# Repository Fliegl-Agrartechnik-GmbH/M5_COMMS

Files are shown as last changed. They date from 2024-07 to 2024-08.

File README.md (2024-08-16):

# M5_COMMS
M5_COMMS are CAN-Bus and Modbus Boards for M5 Stack

<https://github.com/espressif/esp-idf/issues/13989>

<https://community.m5stack.com/topic/306/plc-module/12?_=1718738548748>

4 Models: 
(right klick, open in new Tab for high-res view)

1. MAX3485, is a Fully 3.3V RS-485 Transceiver


2. LTC2877IMSE, is a 5V RS-485 Transceiver with a VIO Pin, so can interface to a 3.3V and even 1.8 V MCU


3. MAX485 is a 5V only Transceiver, using the Schottky Diode to not damage the ESP32 at RX.


4. CAN-Bus with a Infineon Transceiver

see: <https://github.com/Fliegl-Agrartechnik-GmbH/M5_COMMS/tree/main/CAN-BUS>
   


174776340480-Produce_DanZhi SMT_Snapshot Top 2790709A_Y380 SMT02407241857146 (1)

# lic
<p xmlns:cc="http://creativecommons.org/ns#" xmlns:dct="http://purl.org/dc/terms/"><a property="dct:title" rel="cc:attributionURL" href="https://github.com/Fliegl-Agrartechnik-GmbH/M5_COMMS">M5_COMMS</a> by <a rel="cc:attributionURL dct:creator" property="cc:attributionName" href="https://github.com/Fliegl-Agrartechnik-GmbH">Fliegl Agrartechnik GmbH</a> is licensed under <a href="https://creativecommons.org/licenses/by-sa/4.0/?ref=chooser-v1" target="_blank" rel="license noopener noreferrer" style="display:inline-block;">CC BY-SA 4.0</a></p>

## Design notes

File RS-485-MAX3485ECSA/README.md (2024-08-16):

# RS-485-MAX3485ECSA

## Pinout

| **RS-485** | **RXD** | **TXD** | **RTS** |
|---|---|---|---|
| Core (Basic) | G16 | G17 | G2 |
| Core 2 | G13 | G14 | G32 |
| CoreS3 | G18 | G17 | G2 |

## External

| **Pin**  | **1** | **2** | **3** | **4** |
|---|---|---|---|---|
| Function | DC 9-24V | B | A | GND |
| PROFIBUS | DC 9-24V | A | B | GND |

## Testing

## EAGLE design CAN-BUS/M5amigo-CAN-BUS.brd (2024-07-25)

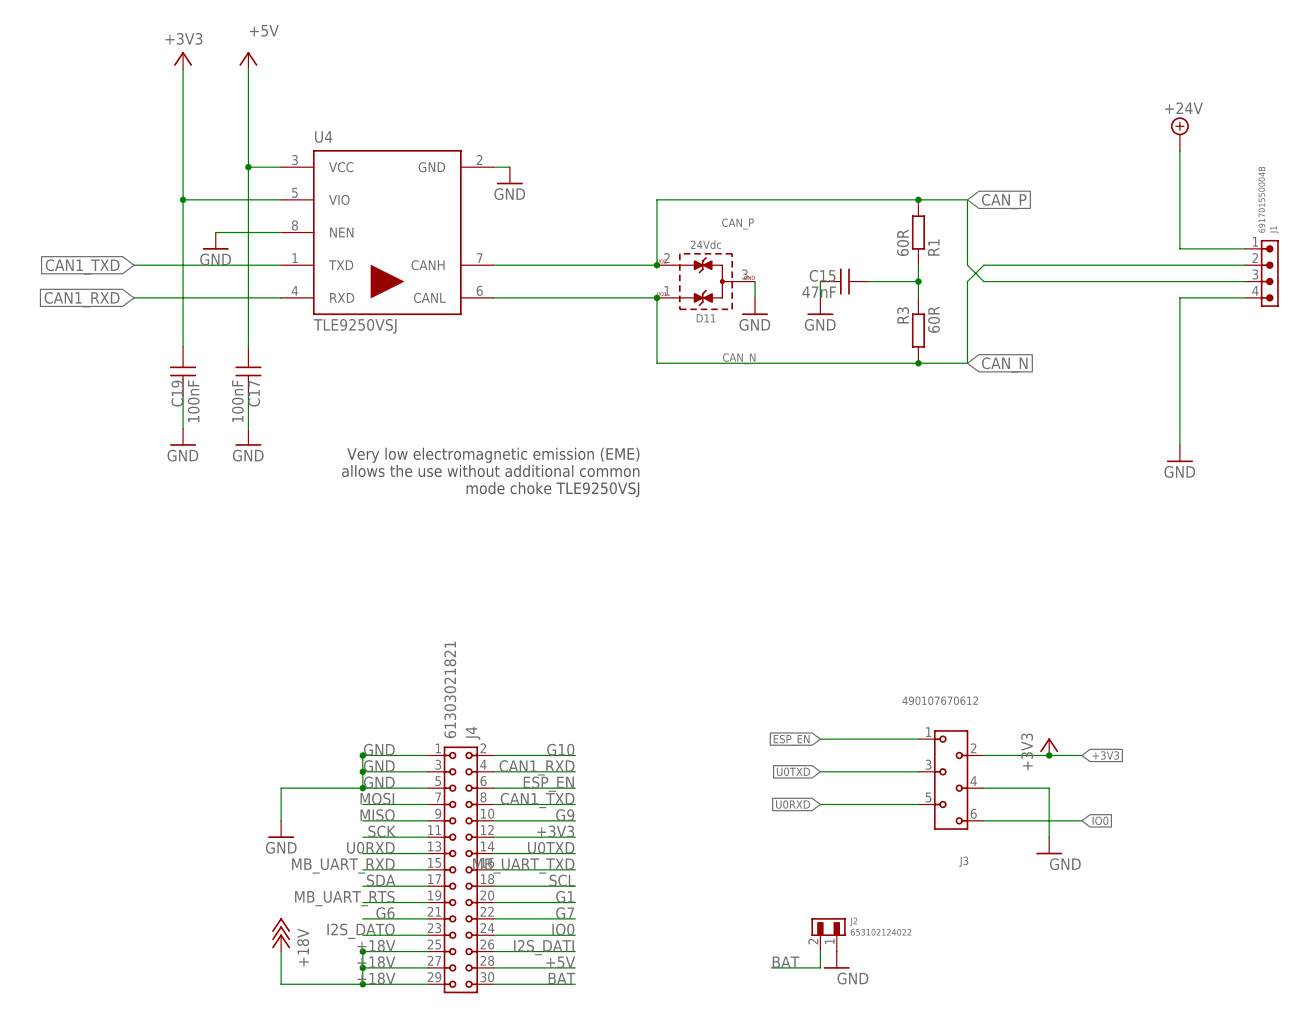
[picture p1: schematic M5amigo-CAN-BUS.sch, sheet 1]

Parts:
C15: 47nF; WCAP-CSGP_0805_H0.8_R
C17, C19: 100nF; WCAP-CSGP_0805_H0.8_R
D11: 24Vdc; WE-TVS_SOT23-3L
J1: 691701550004B
J2: 653102124022
J3: 490107670612; 490107670612_DEBUGGING
J4: 61303021821
R1, R3: 60R; R0805
U4: TLE9250VSJ; SOIC127P602X173-8N-V

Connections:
+3V3: C19.1, J3.2, J4.12, U4.5 (VIO)
+5V: C17.1, J4.28, U4.3 (VCC)
+18V: J4.25, J4.27, J4.29; also elsewhere on the board
+24V: J1.1; also elsewhere on the board
BAT: J2.2, J4.30
CAN1_RXD: J4.4, U4.4 (RXD)
CAN1_TXD: J4.8, U4.1 (TXD)
CAN_N: D11.1 (I/O1), J1.2, R3.2, U4.6 (CANL)
CAN_P: D11.2 (I/O2), J1.3, R1.2, U4.7 (CANH)
ESP_EN: J3.1, J4.6
G1: J4.20
G6: J4.21
G7: J4.22
G9: J4.10
G10: J4.2
GND: C15.2, C17.2, C19.2, D11.3 (GND), J1.4, J2.1, J3.4, J4.1, J4.3, J4.5, U4.2 (GND), U4.8 (NEN); also elsewhere on the board
I2S_DATI: J4.26
I2S_DATO: J4.23
IO0: J3.6, J4.24
MB_UART_RTS: J4.19
MB_UART_RXD: J4.15
MB_UART_TXD: J4.16
MISO: J4.9
MOSI: J4.7
unnamed: C15.1, R1.1, R3.1
SCK: J4.11
SCL: J4.18
SDA: J4.17
U0RXD: J3.5, J4.13
U0TXD: J3.3, J4.14

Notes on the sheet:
Very low electromagnetic emission (EME) allows the use without additional common mode choke TLE9250VSJ

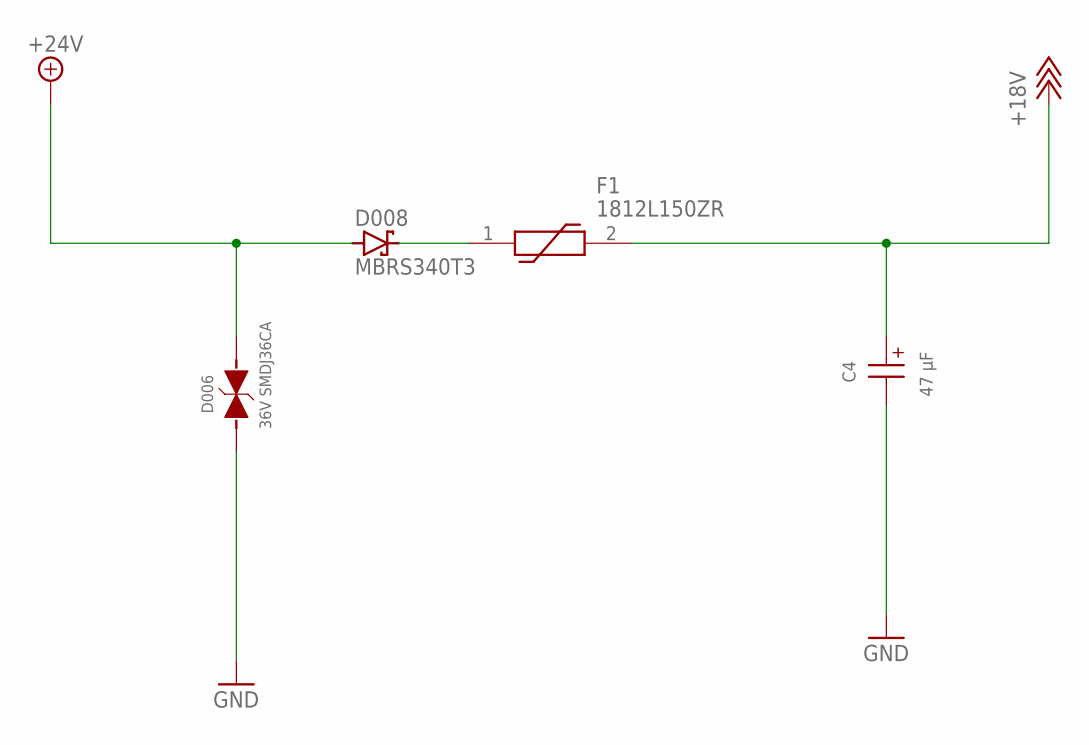
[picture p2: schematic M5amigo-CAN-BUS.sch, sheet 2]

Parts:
C4: 47 µF; WCAP-ASLL_6.3X7.7(DXL)
D006: 36V SMDJ36CA; WE-TVSP_DO-214AB_BIDIRECTIONAL
D008: MBRS340T3; SMC
F1: 1812L150ZR; 1812L010DR

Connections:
+18V: C4.1 (+), F1.2; also elsewhere on the board
+24V: D006.2, D008.A; also elsewhere on the board
GND: C4.2 (-), D006.1; also elsewhere on the board
unnamed: D008.C, F1.1

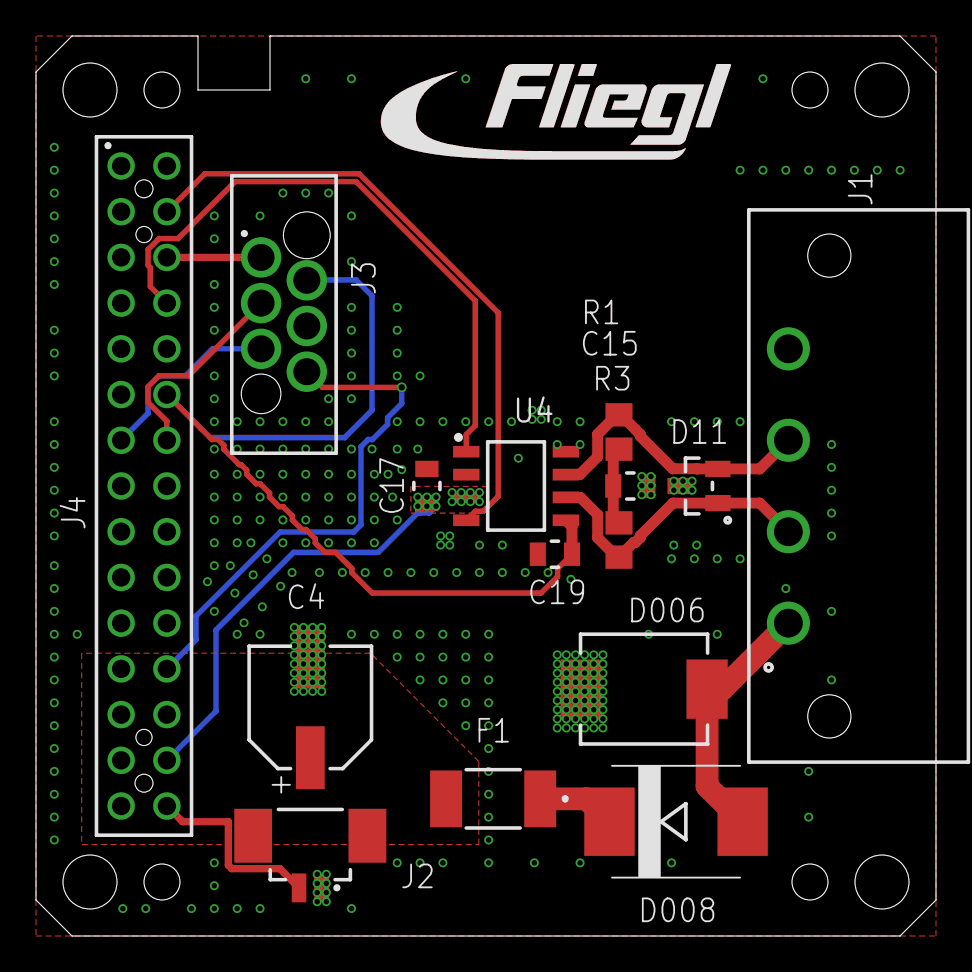
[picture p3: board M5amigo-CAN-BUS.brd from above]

Board: 2 copper layers, 50.0 x 50.0 mm, 16 parts (0 on the bottom side), 16 nets.

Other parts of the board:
U$2: FLIEGL_LOGO_19.5X5.3MM_TOP+TPLACE

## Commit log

2024-07-25 Add gitignore rules for temporary files and add new PCB layout file with layer definitions.
    [M5amigo-CAN-BUS.brd, M5amigo-CAN-BUS.sch, M5amigo-RS-485-LTC2877IMSE.brd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]
2024-08-16 Add README with CAN-BUS pinout and testing link
    A new README file was added with information on CAN-BUS pinout for different cores and external connections. It also includes a link for testing details.

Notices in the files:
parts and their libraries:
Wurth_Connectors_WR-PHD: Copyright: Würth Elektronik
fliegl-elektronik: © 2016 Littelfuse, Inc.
